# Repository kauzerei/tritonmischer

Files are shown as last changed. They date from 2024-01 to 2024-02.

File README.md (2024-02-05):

# Tritonmischer





Matrix audio mixer with 3 stereo inputs and 3 stereo outputs.

You can find the [documentation here on GitHub pages](https://kauzerei.github.io/tritonmischer/).

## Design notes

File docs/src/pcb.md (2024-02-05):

# PCB Layout

This page shows the current version of the PCB layout as SVG graphics.

## DIY PCB Fabrication

If you want to etch a PCB by yourself, use [this PDF of the copper layer](./plot/tritonmischer_pcb_diy.pdf).
You need to fabricate three each of the two left most designs, and one of the remaining design on the right.

<script src="js/svg-pan-zoom.js" charset="UTF-8"></script>
<div style="background-color: white; border: 1px solid black;">
    <embed type="image/svg+xml" src="./plot/tritonmischer_pcb_diy.svg" id="pz_tritonmischer_diy" style="width: 100%;"/>
    <script>
        document.getElementById('pz_tritonmischer_diy').addEventListener('load', function(){
            svgPanZoom(document.getElementById('pz_tritonmischer_diy'), {controlIconsEnabled: true, minZoom: 1.0});
        })
    </script>
</div>

[Direct link to this file](./plot/tritonmischer_pcb_diy.svg).

## 2D PCB Layout

You can also view the [Main-Board PCB layout as PDF](./plot/tritonmischer_pcb.pdf).

<script src="js/svg-pan-zoom.js" charset="UTF-8"></script>
<div style="background-color: white; border: 1px solid black;">
    <embed type="image/svg+xml" src="./plot/tritonmischer_pcb.svg" id="pz_tritonmischer" style="width: 100%;"/>
    <script>
        document.getElementById('pz_tritonmischer').addEventListener('load', function(){
            svgPanZoom(document.getElementById('pz_tritonmischer'), {controlIconsEnabled: true, minZoom: 1.0});
        })
    </script>
</div>

[Direct link to this file](./plot/tritonmischer_pcb.svg).

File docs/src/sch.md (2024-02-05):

# Schematics

This page shows the current version of the schematics as SVG graphics.

You can also view the [schematics as PDF](./plot/tritonmischer_sch.pdf).

{{#include inc_tritonmischer_sch.md}}

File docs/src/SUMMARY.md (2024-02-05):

# Summary

# Tritonmixer

- [Introduction](./introduction.md)
- [Schematics](./sch.md)
- [PCB Layout](./pcb.md)

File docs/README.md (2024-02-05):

# Dispensy Documentation

You can find the [documentation here on GitHub pages](https://kauzerei.github.io/tritonmischer/).
This file is intended for contributors that want to modify this website!

## Dependencies

The PCB SVG files are displayed using [svg-pan-zoom](https://github.com/bumbu/svg-pan-zoom), licensed as `BSD-2-Clause`.
The 3D PCB files are displayed using [modelview](https://github.com/jschobben/modelview), licensed as `MIT`.
Fetch the included git submodules after cloning this repository before working on the docs.

    git submodule update --init

## Local Build

The docs are built using [mdbook](https://github.com/rust-lang/mdBook), licensed as `MPL-2.0`.
Get the [latest release from GitHub](https://github.com/rust-lang/mdBook/releases) for a pre-built binary if you want to test changes to the docs locally.

    ./docs/generate_docs.sh serve

This will open your browser to a local development instance of the docs.

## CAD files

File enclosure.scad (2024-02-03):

bissl=1/100;
$fa=1/1;
$fs=1/2;

part="box";//[box, lid, visualization]

//standoffs for screws
peg_h=5;
peg_id=3.5;
peg_od=2*peg_id;

//box dimentions 
width=100;
depth=119;
height=peg_h+32;
wall=1.6;
floor=1.5;

//lid dimensions
thickness=2;
air=0.5;

//parts positions
power_pos=[1,2+2*26.67+50.8,0]; //measured from schematic
input_pos=[[1,2,0],[1,2+26.67,0],[1,2+2*26.67,0]]; //
output_holes=[ for (i=[0:2]) [21.59+i*29.21,120,peg_h+24]];
cover_pegs=[for (x=[8,92]) for (y=[22,96]) [x,y]];
potis=[for (x=[for (i=[0:2]) 10+21.59+i*29.21]) for (y=[ for (i=[0:2]) 1+7.62+i*26.67]) [x,y]];

module box() {
  difference() {
    translate([-wall, -wall, -floor]) cube([width+2*wall, depth+2*wall, height+floor]);
    cube([width, depth, height+bissl]);
    translate(power_pos)power(false);
    for (tr=input_pos) translate(tr) input(false); 
    for (tr=output_holes) translate(tr) rotate([90,0,0]) cylinder(h=10,d=7,center=true); 
  }
  translate(power_pos) power(true);
  for (tr=input_pos) translate(tr) input(true);
  for (tr=cover_pegs) translate(tr) difference() {
    union() {
      cylinder(h=32,d=peg_od);
      cylinder(h=5,d1=10,d2=0);
    }
    translate([0,0,22]) cylinder(h=32,d=peg_id);
  }
}

module power(positive=true) { //true: parts that need to be added, false: subtracted
  pegs=[[13.97,7.62],[60.96,3.81]]; //power-specific, measured from schematic
  holes=[[0,11.43/2,peg_h+5]];
  if(positive) for (tr=pegs) translate(tr) difference() {
    cylinder(d=peg_od,h=peg_h);
    cylinder(d=peg_id,h=peg_h+bissl);
  }
  else for (tr=holes) translate(tr) rotate([0,90,0]) cylinder(d=7,h=10,center=true); //sorry for hardcoded magic values
}

module input(positive=true) {
  pegs=[[16.51,3.81],[64.77,11.43]]; //output-specific, measured from schematic
  holes=[[0,7.62,peg_h+5]];
  if(positive) for (tr=pegs) translate(tr) difference() {
    cylinder(d=peg_od,h=peg_h);
    cylinder(d=peg_id,h=peg_h+bissl);
  }
  else for (tr=holes) translate(tr) rotate([0,90,0]) cylinder(d=7,h=10,center=true); //sorry for hardcoded magic values
}

module cover () {
  difference() {
    union() {
      translate([-wall, -wall, 0]) cube([width+2*wall, depth+2*wall, thickness]);
      translate([air, air, -thickness]) cube([width-2*air, depth-2*air, thickness]);
    }
    translate([air+wall, air+wall, -thickness-bissl]) cube([width-2*air-2*wall, depth-2*air-2*wall, thickness]);  
    translate ([0,0,-2*bissl]) for (tr=cover_pegs) translate(tr) cylinder(h=thickness+3*bissl,d=2);
    translate ([0,0,-2*bissl]) for (tr=potis) translate(tr) cylinder (h=thickness+3*bissl,d=8);
  }
}

if (part=="box") box();
else if (part=="lid") rotate([180,0,0])cover(); //printed upside down
else {translate([0,0,38]) cover(); box();}

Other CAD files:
case/enclosure.scad

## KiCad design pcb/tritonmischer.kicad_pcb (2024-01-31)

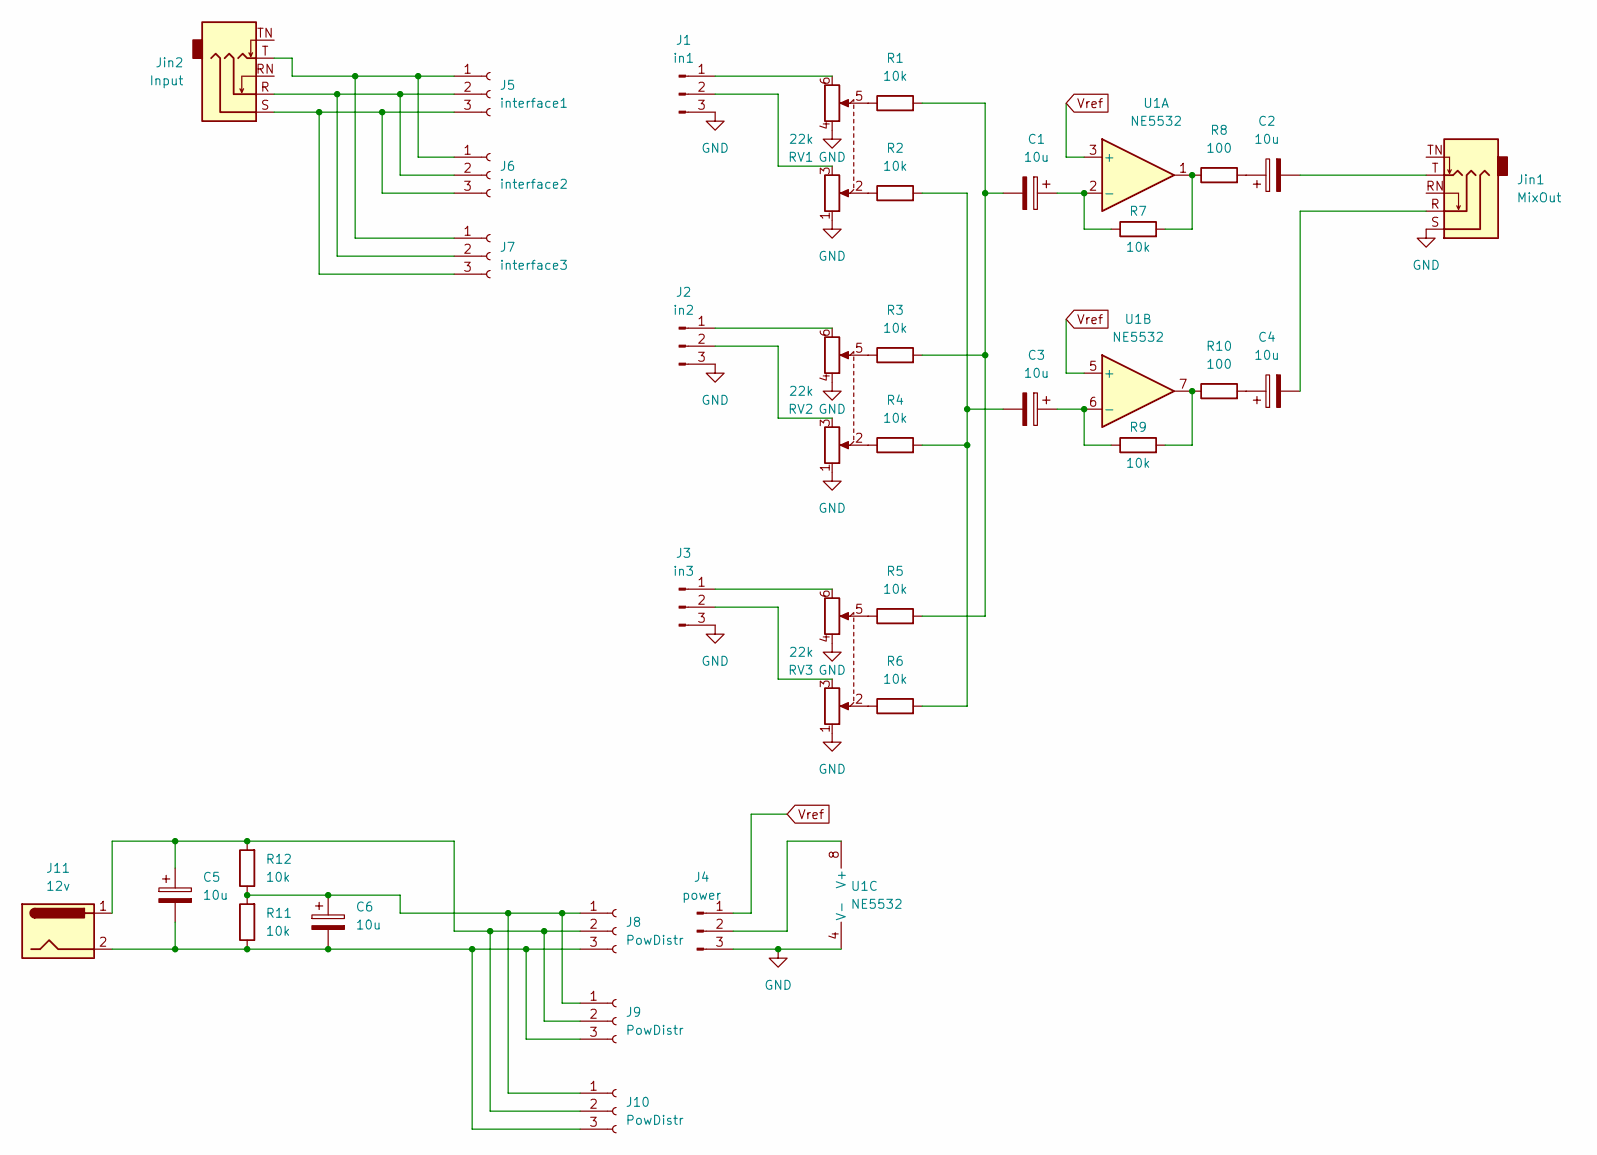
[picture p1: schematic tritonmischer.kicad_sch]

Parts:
C1, C2, C3, C4, C5, C6: 10u; CP_Radial_D8.0mm_P5.00mm
J1: in1; PinHeader_1x03_P2.54mm_Vertical
J2: in2; PinHeader_1x03_P2.54mm_Vertical
J3: in3; PinHeader_1x03_P2.54mm_Vertical
J4: power; PinHeader_1x03_P2.54mm_Vertical
J5: interface1; PinSocket_1x03_P2.54mm_Vertical
J6: interface2; PinSocket_1x03_P2.54mm_Vertical
J7: interface3; PinSocket_1x03_P2.54mm_Vertical
J8, J9, J10: PowDistr; PinSocket_1x03_P2.54mm_Vertical
J11: 12v; JWT_A3963_1x02_P3.96mm_Vertical
Jin1: MixOut; Jack_3.5mm_CUI_SJ1-3525N_Horizontal
Jin2: Input; Jack_3.5mm_CUI_SJ1-3525N_Horizontal
R1, R2, R3, R4, R5, R6: 10k; R_Axial_DIN0204_L3.6mm_D1.6mm_P5.08mm_Vertical
R7, R9, R12: 10k; R_Axial_DIN0204_L3.6mm_D1.6mm_P2.54mm_Vertical
R8, R10: 100; R_Axial_DIN0204_L3.6mm_D1.6mm_P2.54mm_Vertical
R11: 10k; R_Axial_DIN0204_L3.6mm_D1.6mm_P5.08mm_Horizontal
RV1, RV2, RV3: 22k; Potentiometer_Alps_RK163_Dual_Horizontal
U1: NE5532; DIP-8_W7.62mm

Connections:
GND: J1.3, J2.3, J3.3, J4.3, Jin1.S, RV1.1, RV1.4, RV2.1, RV2.4, RV3.1, RV3.4, U1.4 (V-)
unnamed: C1.2, R1.2, R3.2, R5.2
unnamed: C2.1, R8.2
unnamed: C2.2, Jin1.T
unnamed: C3.2, R2.2, R4.2, R6.2
unnamed: C4.1, R10.2
unnamed: C4.2, Jin1.R
unnamed: J1.1, RV1.6
unnamed: J1.2, RV1.3
unnamed: J2.1, RV2.6
unnamed: J2.2, RV2.3
unnamed: J3.1, RV3.6
unnamed: J3.2, RV3.3
unnamed: J4.2, U1.8 (V+)
unnamed: J5.1, J6.1, J7.1, Jin2.T
unnamed: J5.2, J6.2, J7.2, Jin2.R
unnamed: J5.3, J6.3, J7.3, Jin2.S
unnamed: C6.1, J8.1, J9.1, J10.1, R11.2, R12.1
unnamed: C5.1, J8.2, J9.2, J10.2, J11.1, R12.2
unnamed: C5.2, C6.2, J8.3, J9.3, J10.3, J11.2, R11.1
unnamed: R1.1, RV1.5
unnamed: R2.1, RV1.2
unnamed: R3.1, RV2.5
unnamed: R4.1, RV2.2
unnamed: R5.1, RV3.5
unnamed: R6.1, RV3.2
unnamed: R7.2, R8.1, U1.1
unnamed: R9.2, R10.1, U1.7
unnamed: C1.1, R7.1, U1.2 (-)
unnamed: C3.1, R9.1, U1.6 (-)
Vref: J4.1, U1.3 (+), U1.5 (+)

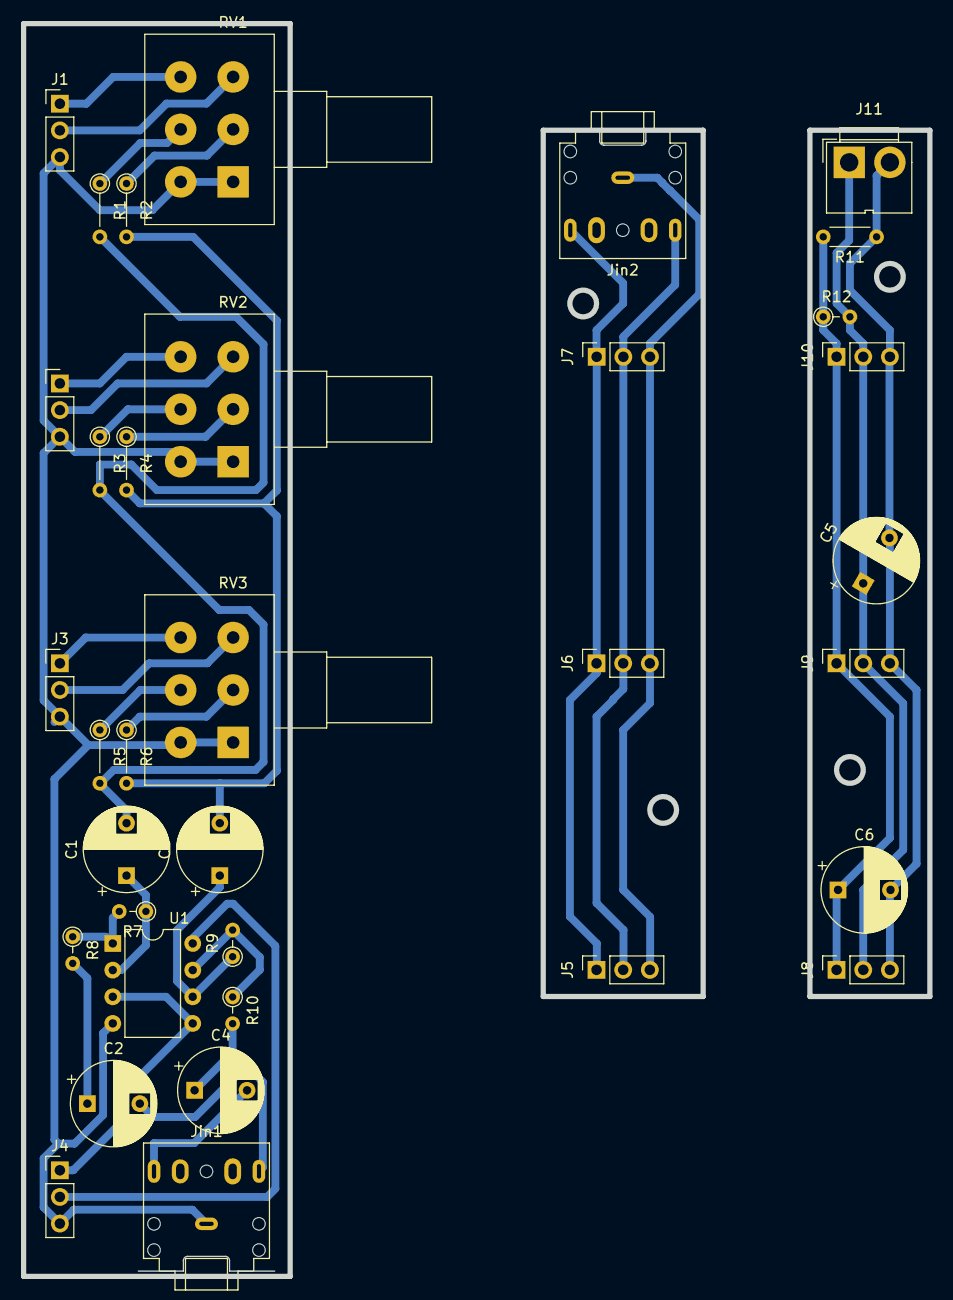
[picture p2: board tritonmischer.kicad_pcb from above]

Board: 2 copper layers, 86.4 x 119.4 mm, 35 parts (0 on the bottom side), 31 nets.

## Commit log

2024-01-27 publish tested schematics
    [mixer.kicad_pcb, mixer.kicad_sch]
2024-01-27 start creating box
    [box.scad, box.stl, mixer.kicad_pcb]
2024-01-31 add box
    [box.scad, box.stl, cover.stl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]
2024-01-31 update box
    [box.scad, box.stl, cover.stl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]
2024-02-03 rename files based on pun
    [box.scad, box.stl, enclosure.scad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]
2024-02-05 add usual docs and workflow stuff
    [box.stl, enclosure.scad, lid.stl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]
